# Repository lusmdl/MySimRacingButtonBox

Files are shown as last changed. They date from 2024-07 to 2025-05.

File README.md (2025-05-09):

# Sim Racing Button Box

Welcome to the Sim Racing Button Controller repository!  

This project is built around an ATmega328P microcontroller, which is configured to manage a button matrix tailored for sim racing setups. 
The system uses I2C communication, where the Arduino Micro acts as the **master** and the ATmega328P functions as the **slave** (Address standard 8).
This ensures precise control and synchronization between the components.  

The ATmega328P transmits a 16-bit signal representing the states of up to 16 buttons **only when requested by the Arduino Micro**. This on-demand communication minimizes latency and ensures efficient data transfer. Additionally, the PCB includes support for a joystick connection, expanding its versatility.  

This project complements [MySimRacingCore](https://github.com/lusmdl/MySimRacingCore), which serves as the brain of the entire sim racing system. Together, they deliver a modular and high-performance solution for sim racing enthusiasts.

## Features

- Support for up to 16 buttons in a matrix configuration
- Seamless I2C communication with the Arduino Micro for precise control
- Fast and effective button state management with Keypad Library
- Joystick integration via the PCB's RJ45 jack, reducing wiring complexity

## Getting Started

### Hardware Requirements

- **ATmega328P Microcontroller**
- 16 Mhz Oscilator
- 12..22 pF Condansator
- 100 µF Condansator for supply stability
- **Button Matrix**: Up to 16 buttons
- **The PCBA from master project**: [MySimRacingCore](https://github.com/lusmdl/MySimRacingCore)

> Example PCB for this project
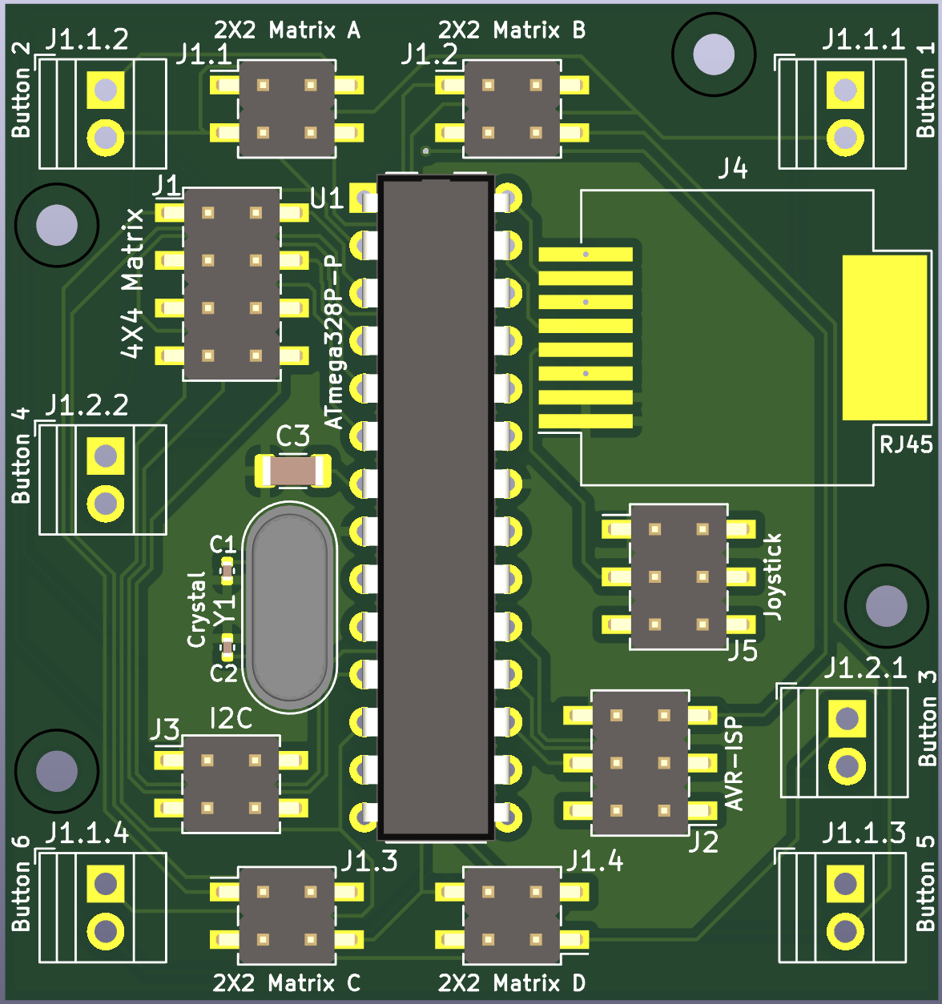
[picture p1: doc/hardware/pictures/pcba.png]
PCBA


### Software Requirements

- [**PlatformIO**](https://platformio.org/install/ide?install=vscode): Used for programming the ATmega328P microcontroller.
- [**Wire.h**](https://www.arduino.cc/en/Reference/Wire): for I2C communication
- [**AVR Lib**](https://github.com/avrdudes/avr-libc.git): standard lib with PlatformIO.
- [**Keypad Library**](https://github.com/Chris--A/Keypad.git): Used for the 4x4 Matrix

### Software Installation and Setup

> You can either use the precompiled HEX file or compile the firmware yourself.

1. **Install PlatformIO**  
   - Set up PlatformIO in your preferred development environment (e.g., VSCode or Atom) by following the official [installation guide](https://platformio.org/install).  

2. **Clone the Repository**  

   ```sh
   git clone https://github.com/lusmdl/MySimRacingButtonBox.git
   ```  

**3. Open the Project**  
- Open the cloned repository in your PlatformIO environment.  
- Update the line `#define I2C_ADDR            8` in [ProjectConfig.hpp](/include/ProjectConfig.hpp) to match your I²C master device configuration.

> The default address is 8. If you intend to connect this device twice, use addresses 8 and 9. The master will handle the rest.

4. **Build and Upload**  
   - Prepare your ATmega328P-based PCB for flashing. It’s recommended to first flash the firmware onto an Arduino Uno and then transfer the chip to your custom environment.  
   - Build and upload the code using PlatformIO:  

   ```sh
   pio run --target upload
   ```  

### Hardware Setup

1. Assemble the PCB according to the provided design.  
2. Ensure all components, such as the button matrix and joystick, are correctly connected.

## Usage

1. **Hardware Connection**  
   - Connect the button matrix to the ATmega328P as per the configuration.  
   - Establish an I2C connection between the ATmega328P and the Arduino Micro.  

2. **Running the Firmware**  
   - Power on your system.  
   - The ATmega328P will only send a 16-bit signal to the Arduino Micro when requested over I2C, ensuring efficient communication.

## Documentation

- **Software**: [doc/software/html/index.html](doc/software/html/index.html)

## Contributing

We welcome contributions from the community!

First, read the [general contributing conventions for projects from me](CONTRIBUTING.md).

1. Fork the repository.
2. Create a new branch (`git checkout -b feature-branch`).
3. Commit your changes (`git commit -am 'Add new feature'`).
4. Push to the branch (`git push origin feature-branch`).
5. Create a new Pull Request.

## License

This project is licensed under the MIT License - see the [LICENSE](LICENSE) file for details.

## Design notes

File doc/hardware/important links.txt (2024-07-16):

https://docs.arduino.cc/learn/communication/wire/

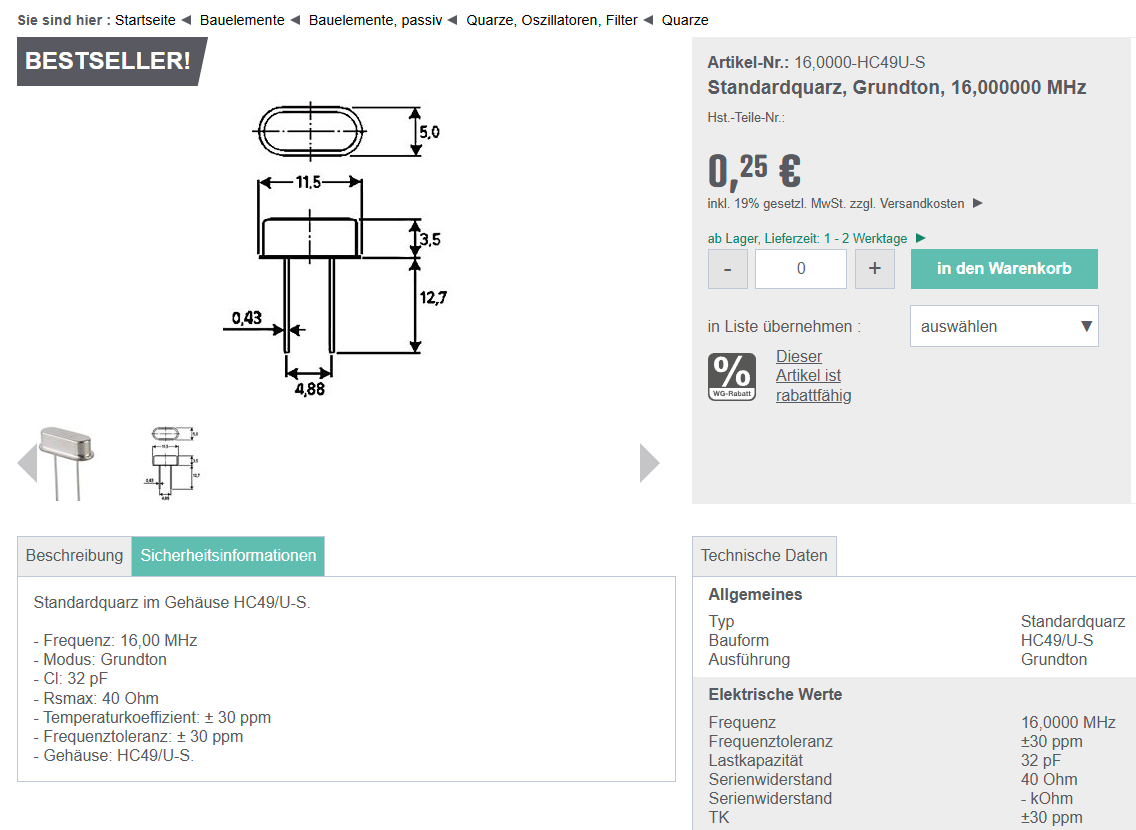
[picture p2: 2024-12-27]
doc/hardware/16mhz Quarz.png

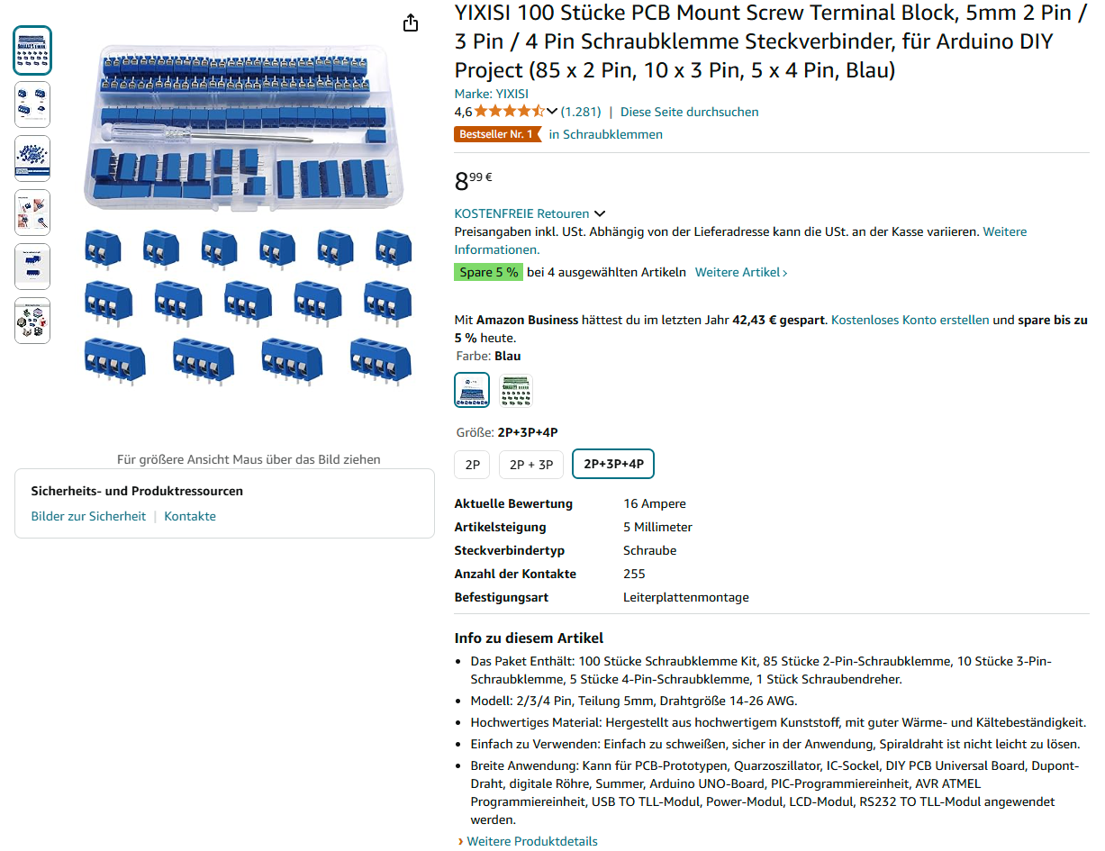
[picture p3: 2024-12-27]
doc/hardware/Srew terminal block.png

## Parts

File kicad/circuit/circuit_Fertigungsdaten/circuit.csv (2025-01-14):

ID | Bezeichner | Footprint | Stückzahl | Bezeichnung | Anbieter und Referenz
1 | J1.1.3 | TerminalBlock_Xinya_XY308-2.54-2P_1x02_P2.54mm_Horizontal | 1 | Button 5
2 | J1.1.1 | TerminalBlock_Xinya_XY308-2.54-2P_1x02_P2.54mm_Horizontal | 1 | Button 1
3 | J1.3 | PinHeader_2x02_P2.54mm_Vertical_SMD | 1 | 2X2 Matrix C
4 | C2,C1 | C_0402_1005Metric | 2 | 12..22 pF
5 | J3 | PinHeader_2x02_P2.54mm_Vertical_SMD | 1 | I2C
6 | J5 | PinHeader_2x03_P2.54mm_Vertical_SMD | 1 | Joystick
7 | J1.1.2 | TerminalBlock_Xinya_XY308-2.54-2P_1x02_P2.54mm_Horizontal | 1 | Button 2
8 | J4 | RJ45_Molex_0855135013_Vertical | 1 | RJ45
9 | J1.2.2 | TerminalBlock_Xinya_XY308-2.54-2P_1x02_P2.54mm_Horizontal | 1 | Button 4
10 | U1 | DIP-28_W7.62mm | 1 | ATmega328P-P
11 | J2 | PinHeader_2x03_P2.54mm_Vertical_SMD | 1 | AVR-ISP
12 | J1.2 | PinHeader_2x02_P2.54mm_Vertical_SMD | 1 | 2X2 Matrix B
13 | Y1 | Crystal_HC18-U_Vertical | 1 | Crystal
14 | J1.2.1 | TerminalBlock_Xinya_XY308-2.54-2P_1x02_P2.54mm_Horizontal | 1 | Button 3
15 | J1.4 | PinHeader_2x02_P2.54mm_Vertical_SMD | 1 | 2X2 Matrix D
16 | J1 | PinHeader_2x04_P2.54mm_Vertical_SMD | 1 | 4X4 Matrix
17 | J1.1.4 | TerminalBlock_Xinya_XY308-2.54-2P_1x02_P2.54mm_Horizontal | 1 | Button 6
18 | C3 | C_1206_3216Metric | 1 | 10 µF
19 | J1.1 | PinHeader_2x02_P2.54mm_Vertical_SMD | 1 | 2X2 Matrix A

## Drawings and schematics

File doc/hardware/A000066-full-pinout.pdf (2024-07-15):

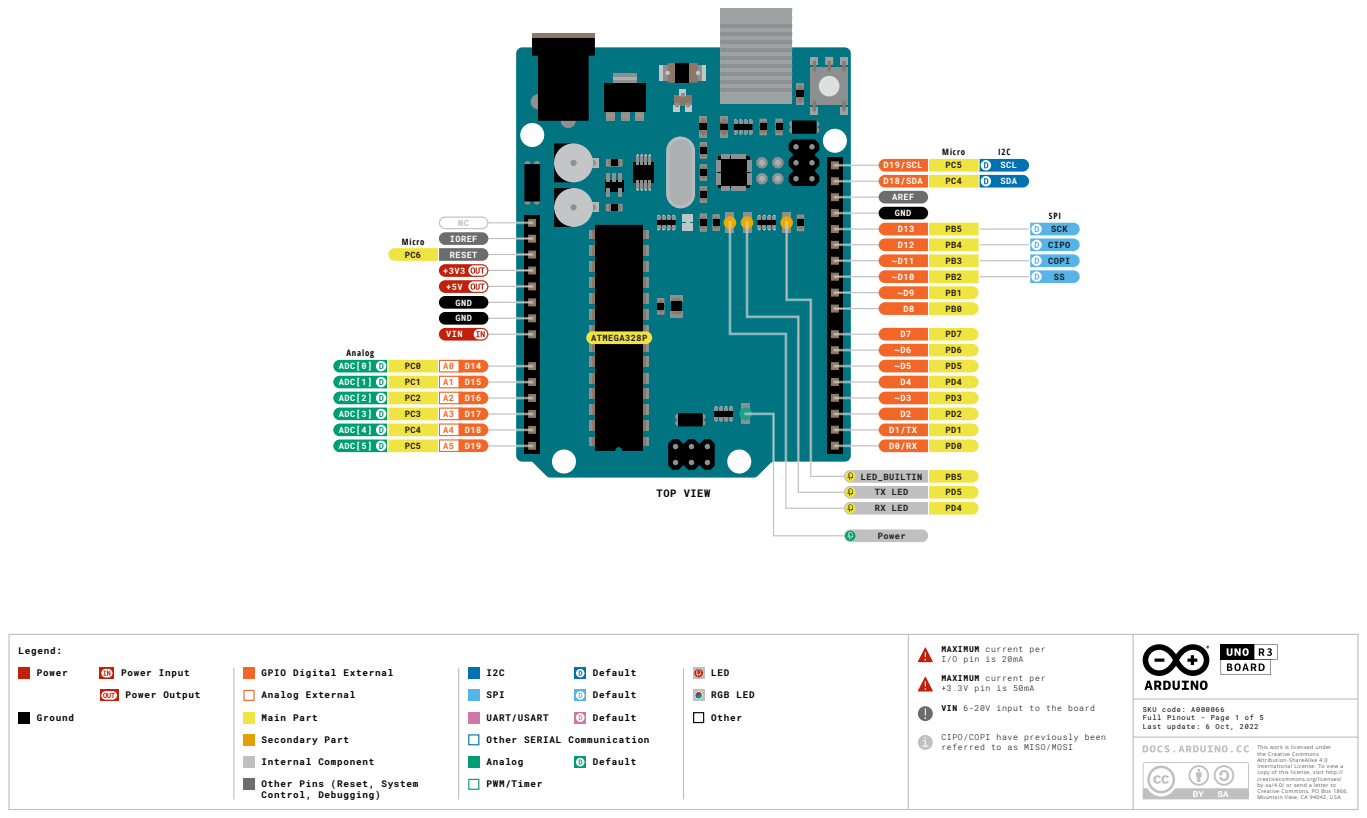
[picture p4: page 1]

PC2 | A2
PC3 | A3

MAXIMUM current per
I/O pin is 20mA
+3.3V pin is 50mA
VIN 6-20V input to the board

GPIO Digital External
Analog External
Main Part
Secondary Part
Internal Component
Other Pins (Reset, System
Control, Debugging)

SKU code: A000066
Full Pinout - Page 1 of 5
Last update: 6 Oct, 2022

CIPO/COPI have previously been
referred to as MISO/MOSI

This work is licensed under
the Creative Commons
Attribution-ShareAlike 4.0
International License. To view a
copy of this license, visit http://
creativecommons.org/licenses/
by-sa/4.0/ or send a letter to
Creative Commons, PO Box 1866,
Mountain View, CA 94042, USA.

# WARNING!

# Advanced Section

# The following information is for advanced use only and may not be officially supported by Arduino software

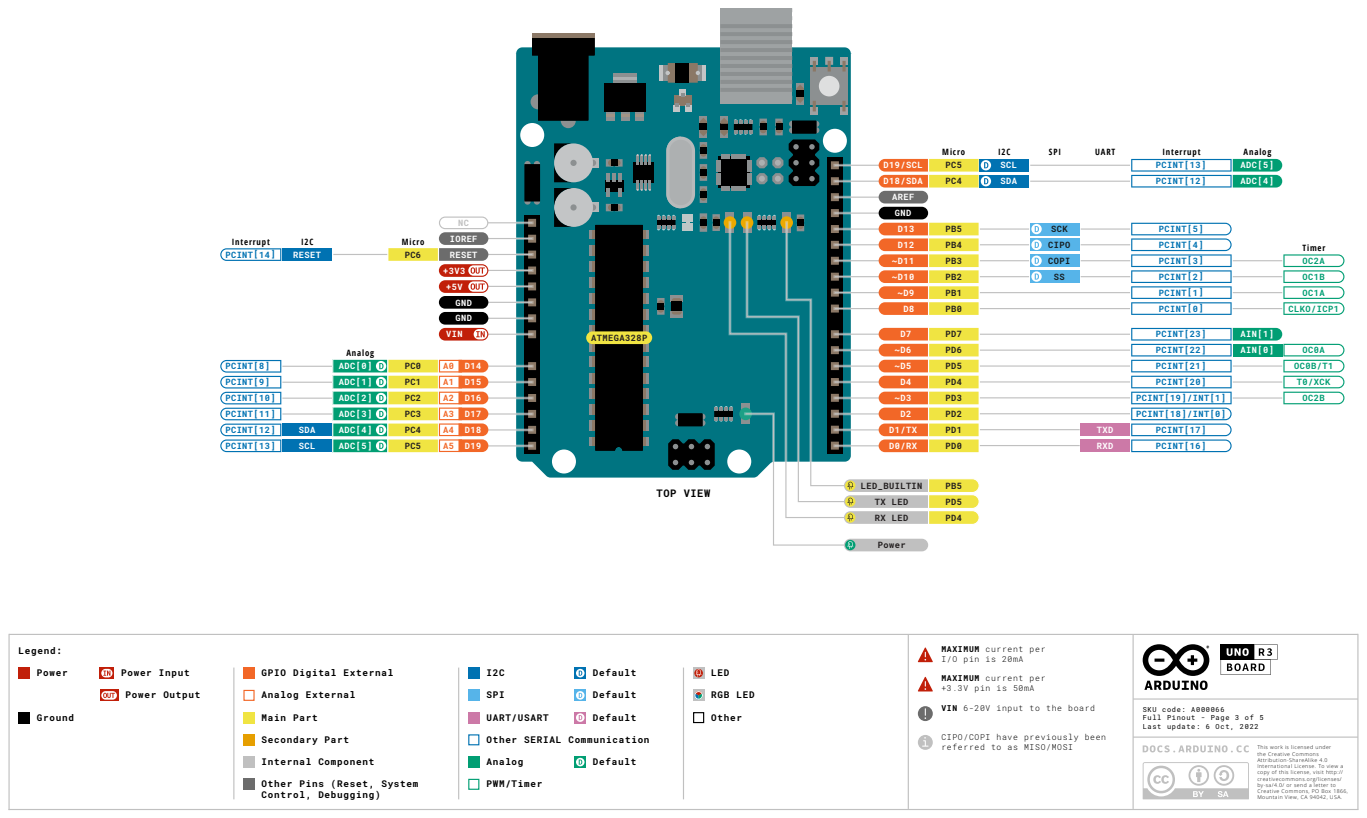
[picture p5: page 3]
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

SKU code: A000066
Full Pinout - Page 3 of 5
Last update: 6 Oct, 2022

CIPO/COPI have previously been

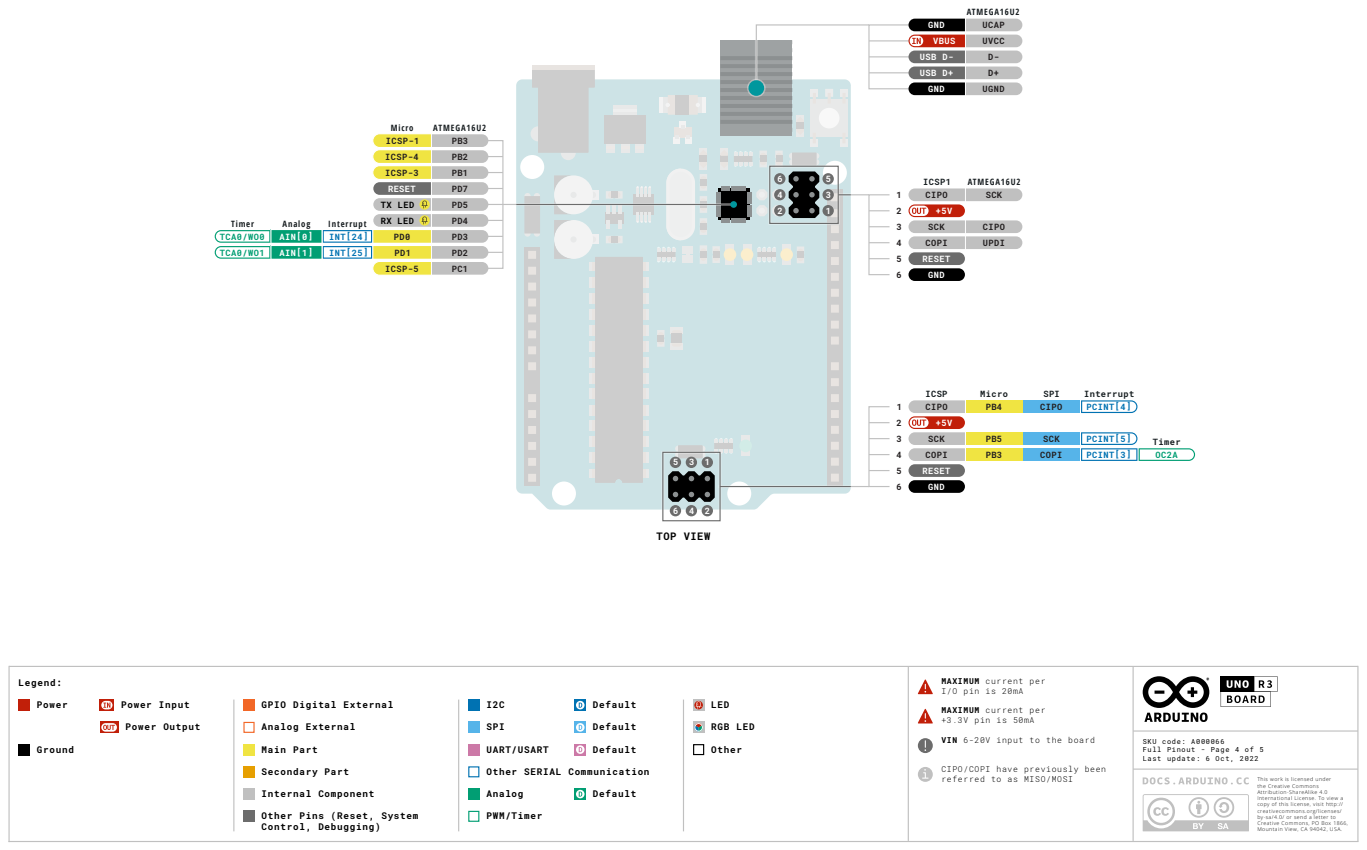
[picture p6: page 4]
Legend:; Power; Power Input; Power Output; Ground; Default; SPI; UART/USART; LED; RGB LED; Other; TOP VIEW; Micro; ATMEGA16U2; Timer; Analog; Interrupt; TCA0/WO0 TCA0/WO1; ICSP-1 ICSP-4 ICSP-3 RESET TX LED RX LED PD0 PD1 ICSP-5; INT[24] INT[25]; AIN[0] AIN[1]; SCK; CIPO UPDI; 1 CIPO 2 +5V 3 SCK 4 COPI 5 RESET 6 GND; ICSP1; ICSP; CIPO; COPI; PCINT[4]; PCINT[5] PCINT[3]; GND; UCAP; VBUS; UVCC; USB D-; USB D+; UGND

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

GPIO Digital External
Analog External
Main Part
Secondary Part

Other SERIAL Communication

SKU code: A000066
Full Pinout - Page 4 of 5
Last update: 6 Oct, 2022

CIPO/COPI have previously been

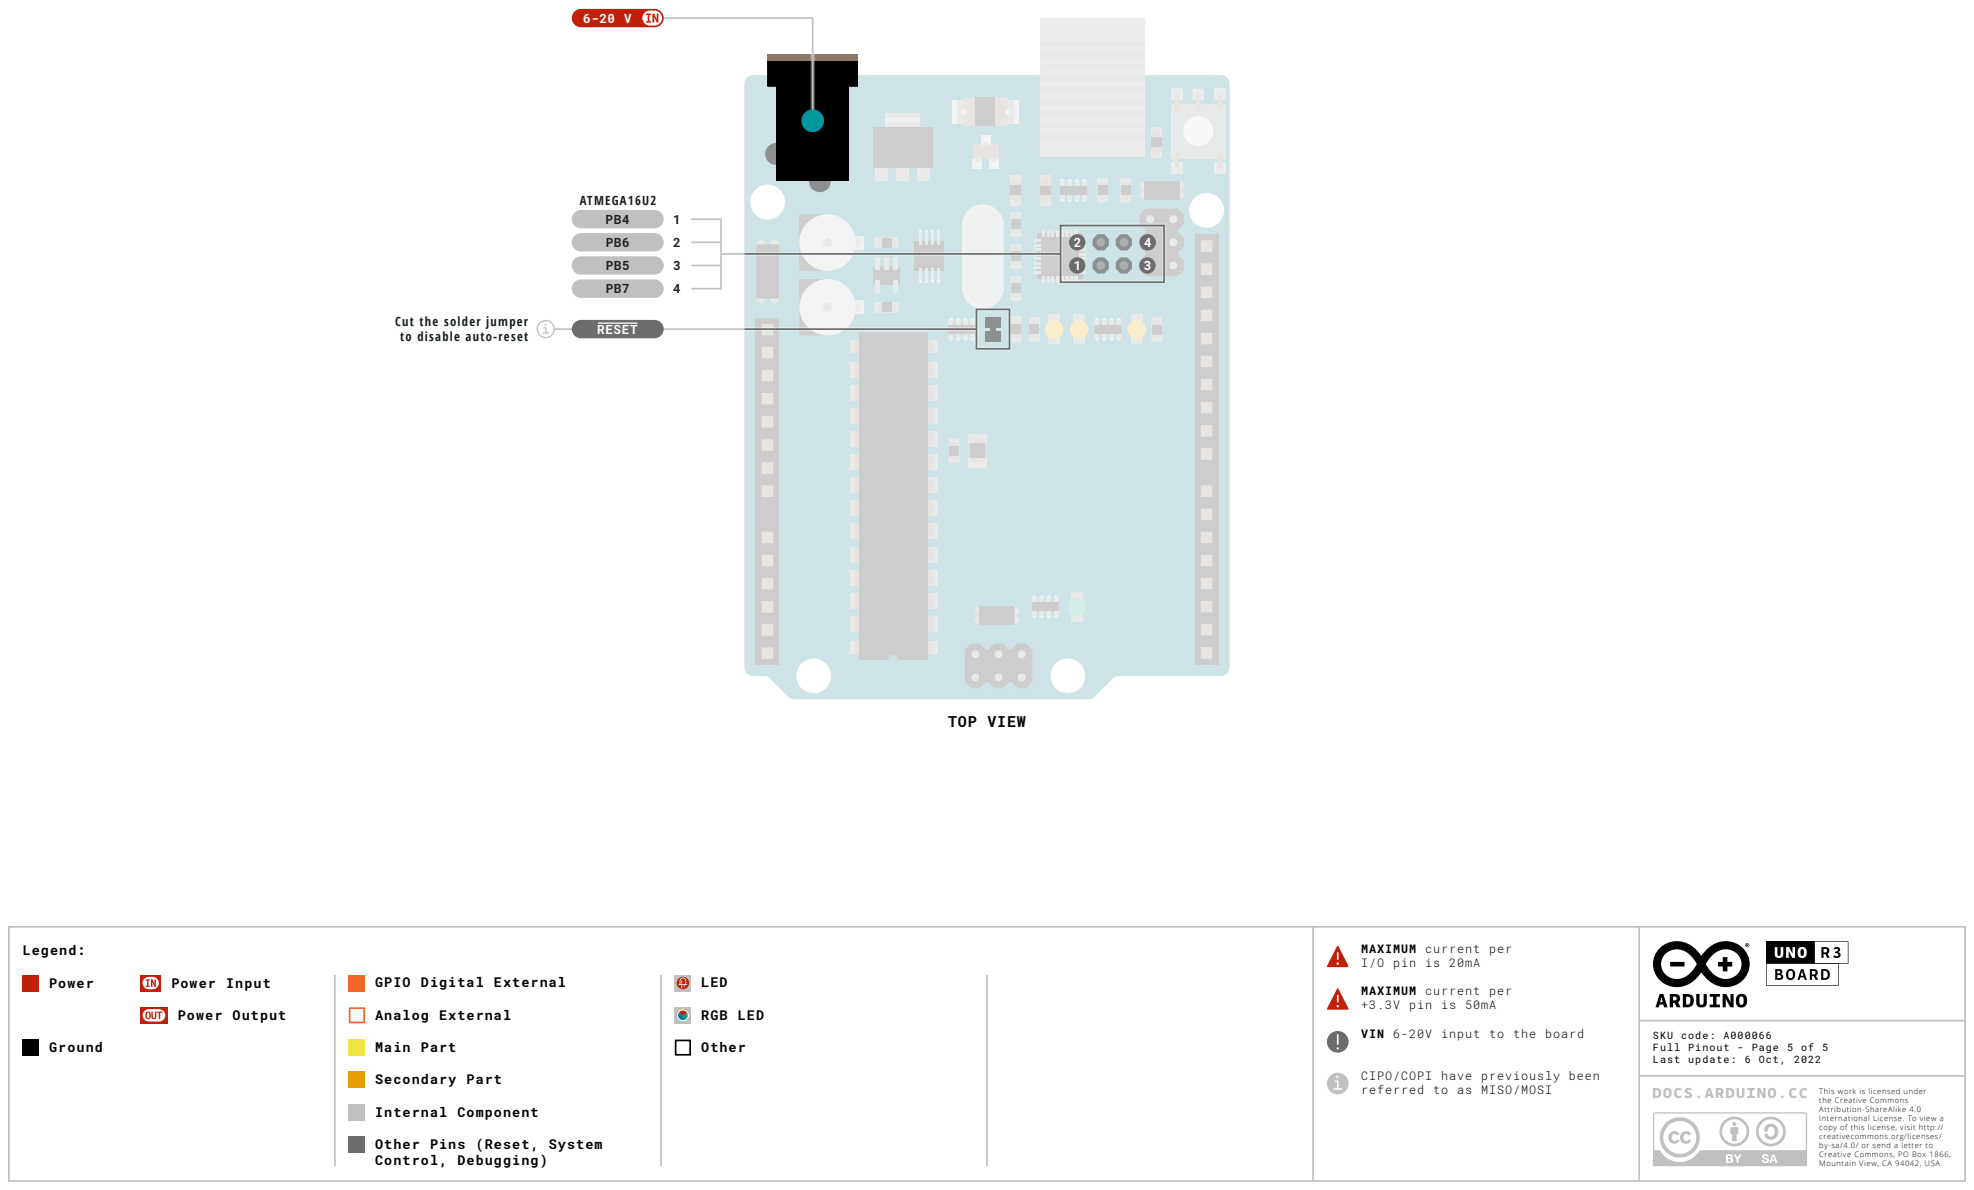
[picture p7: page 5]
Legend:; Power; Power Input; Power Output; Ground; LED; RGB LED; Other; TOP VIEW; ATMEGA16U2 PB4 PB6 PB5 PB7; RESET

Cut the solder jumper
to disable auto-reset

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

GPIO Digital External
Analog External
Main Part
Secondary Part

SKU code: A000066
Full Pinout - Page 5 of 5
Last update: 6 Oct, 2022

CIPO/COPI have previously been

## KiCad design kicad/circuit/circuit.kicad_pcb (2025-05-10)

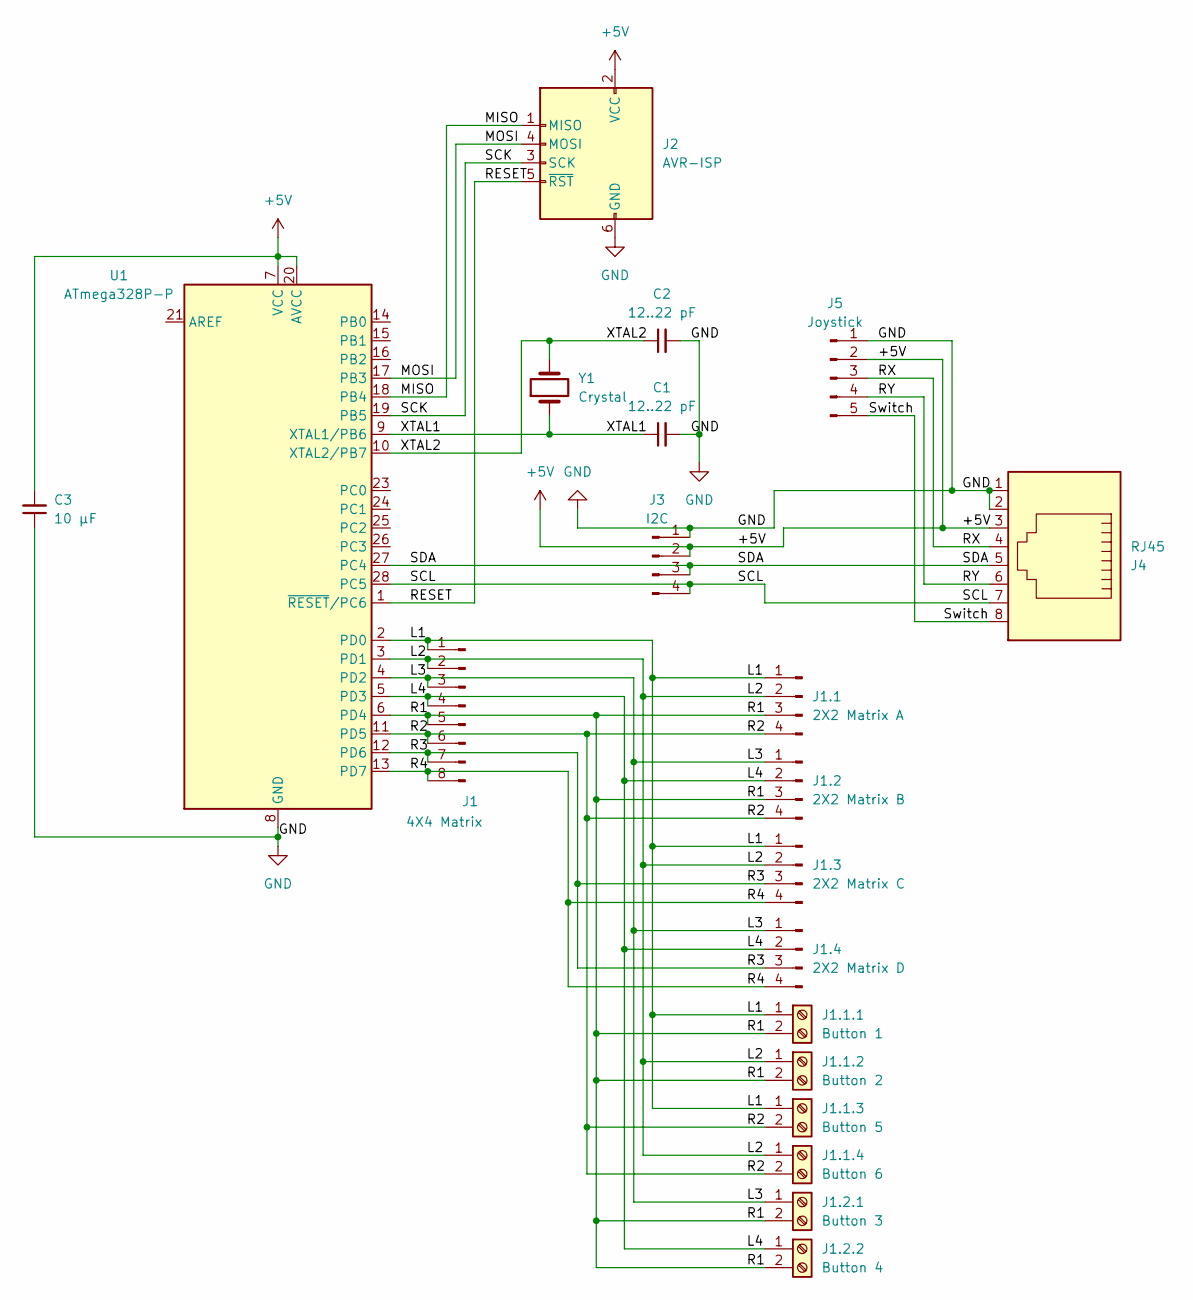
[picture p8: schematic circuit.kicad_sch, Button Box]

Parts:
C1, C2: 12..22 pF; C_0402_1005Metric
C3: 10 µF; C_1206_3216Metric
J1: 4X4 Matrix; PinHeader_2x04_P2.54mm_Vertical_SMD
J1.1: 2X2 Matrix A; PinHeader_2x02_P2.54mm_Vertical_SMD
J1.1.1: Button 1; TerminalBlock_Xinya_XY308-2.54-2P_1x02_P2.54mm_Horizontal
J1.1.2: Button 2; TerminalBlock_Xinya_XY308-2.54-2P_1x02_P2.54mm_Horizontal
J1.1.3: Button 5; TerminalBlock_Xinya_XY308-2.54-2P_1x02_P2.54mm_Horizontal
J1.1.4: Button 6; TerminalBlock_Xinya_XY308-2.54-2P_1x02_P2.54mm_Horizontal
J1.2: 2X2 Matrix B; PinHeader_2x02_P2.54mm_Vertical_SMD
J1.2.1: Button 3; TerminalBlock_Xinya_XY308-2.54-2P_1x02_P2.54mm_Horizontal
J1.2.2: Button 4; TerminalBlock_Xinya_XY308-2.54-2P_1x02_P2.54mm_Horizontal
J1.3: 2X2 Matrix C; PinHeader_2x02_P2.54mm_Vertical_SMD
J1.4: 2X2 Matrix D; PinHeader_2x02_P2.54mm_Vertical_SMD
J2: AVR-ISP; PinHeader_2x03_P2.54mm_Vertical_SMD
J3: I2C; PinHeader_2x02_P2.54mm_Vertical_SMD
J4: RJ45; RJ45_Molex_0855135013_Vertical
J5: Joystick; PinHeader_2x03_P2.54mm_Vertical_SMD
U1: ATmega328P-P; DIP-28_W7.62mm
Y1: Crystal; Crystal_HC18-U_Vertical

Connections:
+5V: C3.2, J2.2 (VCC), J3.2, J4.3, J5.2, U1.7 (VCC), U1.20 (AVCC)
/L1: J1.1, J1.1.1, J1.1.1.1, J1.1.3.1, J1.3.1, U1.2 (PD0)
/L2: J1.2, J1.1.2, J1.1.2.1, J1.1.4.1, J1.3.2, U1.3 (PD1)
/L3: J1.3, J1.2.1, J1.2.1.1, J1.4.1, U1.4 (PD2)
/L4: J1.4, J1.2.2, J1.2.2.1, J1.4.2, U1.5 (PD3)
/MISO: J2.1 (MISO), U1.18 (PB4)
/MOSI: J2.4 (MOSI), U1.17 (PB3)
/R1: J1.5, J1.1.3, J1.1.1.2, J1.1.2.2, J1.2.3, J1.2.1.2, J1.2.2.2, U1.6 (PD4)
/R2: J1.6, J1.1.4, J1.1.3.2, J1.1.4.2, J1.2.4, U1.11 (PD5)
/R3: J1.7, J1.3.3, J1.4.3, U1.12 (PD6)
/R4: J1.8, J1.3.4, J1.4.4, U1.13 (PD7)
/RESET: J2.5 (~RST), U1.1 (~RESET/PC6)
/RX: J4.4, J5.3
/RY: J4.6, J5.4
/SCK: J2.3 (SCK), U1.19 (PB5)
/SCL: J3.4, J4.7, U1.28 (PC5)
/SDA: J3.3, J4.5, U1.27 (PC4)
/Switch: J4.8, J5.5
/XTAL1: C1.1, U1.9 (XTAL1/PB6), Y1.1
/XTAL2: C2.1, U1.10 (XTAL2/PB7), Y1.2
GND: C1.2, C2.2, C3.1, J2.6 (GND), J3.1, J4.1, J4.2, J5.1, U1.8 (GND), U1.22 (GND)

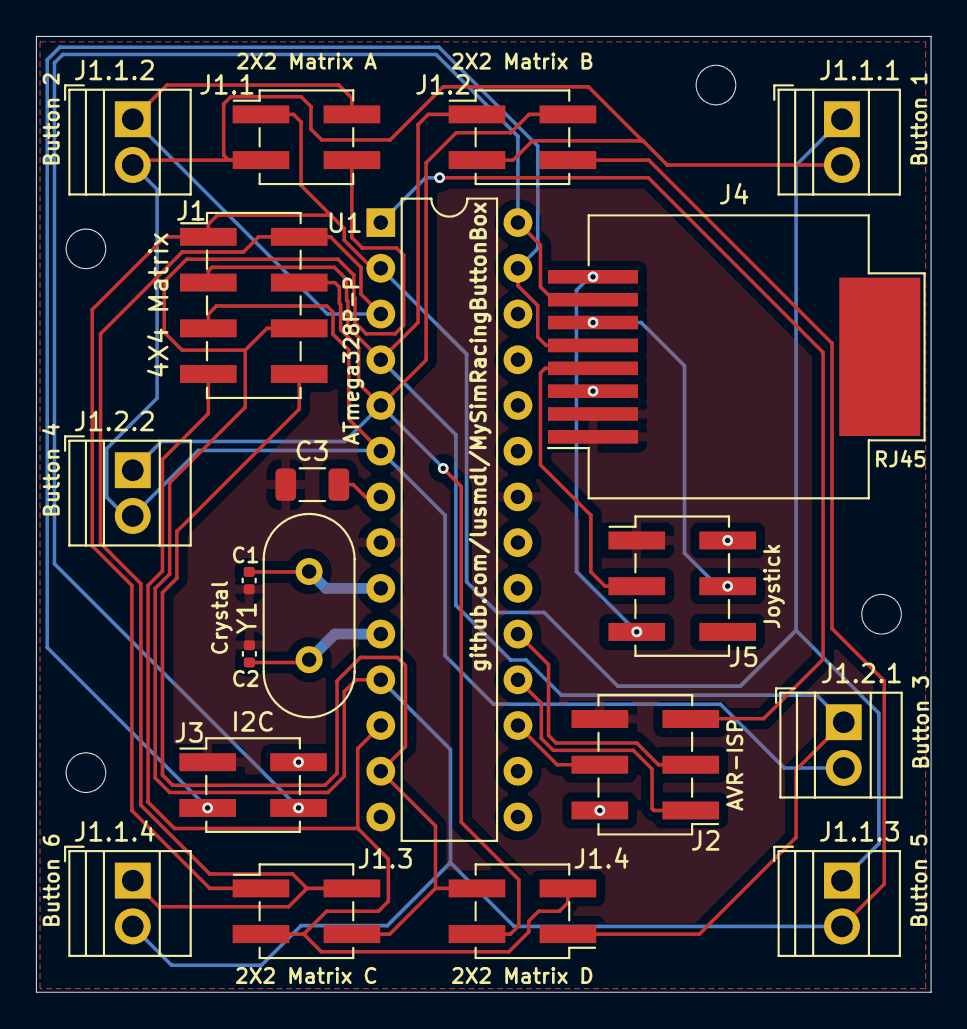
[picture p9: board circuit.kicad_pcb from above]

Board: 2 copper layers, 49.7 x 53.1 mm, 20 parts (0 on the bottom side), 21 nets.

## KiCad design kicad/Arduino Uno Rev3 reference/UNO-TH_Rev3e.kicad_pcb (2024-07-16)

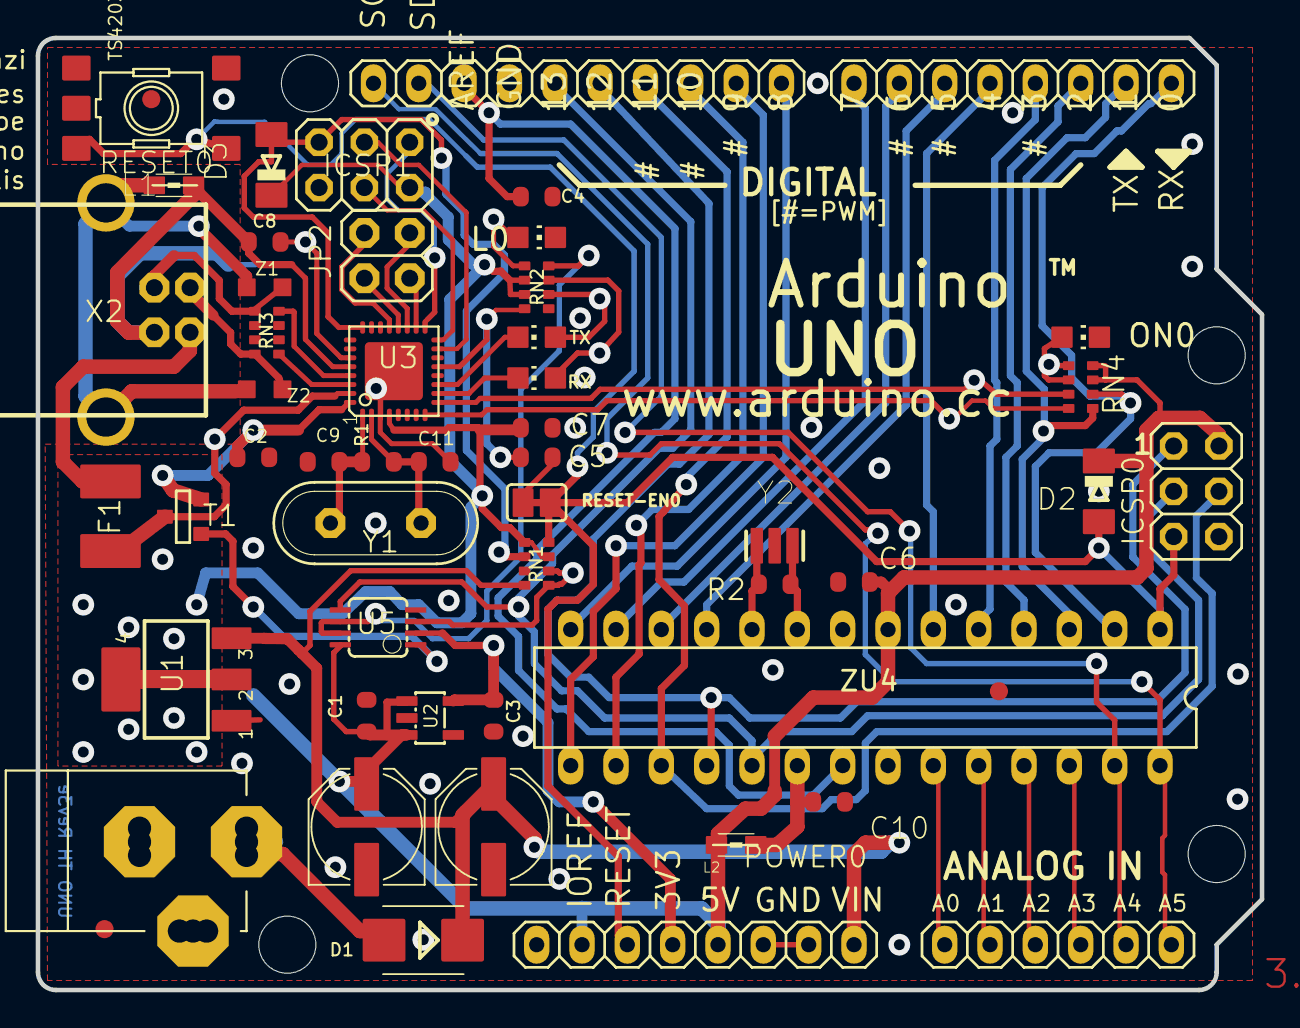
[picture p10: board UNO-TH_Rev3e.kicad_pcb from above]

Board: 2 copper layers, 68.6 x 53.3 mm, 120 parts (1 on the bottom side), 61 nets.

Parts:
@HOLE0, @HOLE1, @HOLE2, @HOLE3: (no value)
AD0: 6x1F-H8.5; 1X06
C1, C2, C4, C5, C6, C7, C10: 100n; C0603-ROUND
C3, C8: 1u; C0603-ROUND
C9, C11: 22p; C0603-ROUND
D1: M7; SMB
D2, D3: CD1206-S01575; MINIMELF
F1: MF-MSMF050-2 500mA; L1812
FD1, FD2, FD3: FIDUCIALMOUNT; FIDUCIA-MOUNT
FRAME1: DNP; FRAME
GND_TP0, GND_TP1: TP_SP; TP-SP
GROUND0: SJ
ICSP0, ICSP1: 3x2 M; 2X03
IOH0: 10x1F-H8.5; 1X10
IOL0: 8x1F-H8.5; 1X08
JP2: 2x2 M - NM; 2X02
L0: YELLOW; CHIP-LED0805
L1: BLM21; 0805
L2: 10uH; 0805
ON0: GREEN; CHIP-LED0805
ORIGIN0: TP_SP; TP-SP
PC1, PC2: 47u; PANASONIC_D
POWER0: 8x1F-H8.5; 1X08
R1, R2: 1M; R0603-ROUND
RESET0: TS42031-160R-TR-7260; TS42
RESET-EN0: SJ
RN1: 10K; CAY16
RN2, RN4: 1K; CAY16
RN3: 22R; CAY16
RX0: YELLOW; CHIP-LED0805
T1: FDN340P; SOT-23
TP_0, TP_1, TP_2, TP_3, TP_3V3, TP_4, TP_5, TP_5V0, TP_5V1, TP_6, TP_7, TP_8, TP_9, TP_10, TP_11, TP_12, TP_13: TP_SP; TP-SP
TP_A0, TP_A1, TP_A2, TP_A3, TP_A4, TP_A5: TP_SP; TP-SP
TP_AREF0: TP_SP; TP-SP
TP_CMP0: TP_SP; TP-SP
TP_D+0: TP_SP; TP-SP
TP_D-0: TP_SP; TP-SP
TP_DTR0: TP_SP; TP-SP
TP_GATE0: TP_SP; TP-SP
TP_LCMD0: TP_SP; TP-SP
TP_LL0: TP_SP; TP-SP
TP_MISO2: TP_SP; TP-SP
TP_MOSI2: TP_SP; TP-SP
TP_ONL0: TP_SP; TP-SP
TP_PB4, TP_PB5, TP_PB6, TP_PB7: TP_SP; TP-SP
TP_PWRIN0: TP_SP; TP-SP
TP_RESET0, TP_RESET2: TP_SP; TP-SP
TP_RX0: TP_SP; TP-SP
TP_RXL0: TP_SP; TP-SP
TP_SCK2: TP_SP; TP-SP
TP_SCL0: TP_SP; TP-SP
TP_SDA0: TP_SP; TP-SP
TP_TX0: TP_SP; TP-SP
TP_TXL0: TP_SP; TP-SP
TP_UGND0: TP_SP; TP-SP
TP_USBVCC0: TP_SP; TP-SP
TP_USH0: TP_SP; TP-SP
TP_VIN0: TP_SP; TP-SP
TP_VUCAP0: TP_SP; TP-SP
TP_XT1, TP_XT2, TP_XT3, TP_XT4: TP_SP; TP-SP
TP_XUSB0: TP_SP; TP-SP
TX0: YELLOW; CHIP-LED0805
U1: NCP1117ST50T3G; SOT223
U2: LP2985-33DBVR; SOT23-DBV
U3: ATMEGA16U2-MU(R); MLF32
U5: LMV358IDGKR; MSOP08
X1: POWERSUPPLY_DC21MMX; POWERSUPPLY_DC-21MM
X2: USB-B_TH; PN61729
Y1: 16MHz; QS
Y2: CSTCE16M0V53-R0 16MHZ; RESONATOR
Z1, Z2: CG0603MLC-05E; CT_CN0603
ZU4: ATMEGA328P-PU; DIL28-3

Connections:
+3V3: C3.2, POWER0.4, TP_3V3.X, U2.5, U5.2
+5V: C1.2, C2.2, C6.2, C7.1, D2.C, D3.C, ICSP0.2, ICSP1.2, L2.1, PC2.+, POWER0.2, POWER0.5, RN1.3, RN1.5, RN2.2, RN2.3, RN4.3, RN4.4, T1.2, TP_5V0.X, TP_5V1.X, U1.2, U1.4, U2.1, U2.3, U3.4, U3.32, U5.8, ZU4.7
AD0: AD0.1, TP_A0.X, ZU4.23
AD1: AD0.2, TP_A1.X, ZU4.24
AD2: AD0.3, TP_A2.X, ZU4.25
AD3: AD0.4, TP_A3.X, ZU4.26
AD4/SDA: AD0.5, IOH0.9, TP_A4.X, TP_SDA0.X, ZU4.27
AD5/SCL: AD0.6, IOH0.10, TP_A5.X, TP_SCL0.X, ZU4.28
AREF: C4.2, IOH0.8, TP_AREF0.X, ZU4.21
AVCC: C10.2, L2.2, ZU4.20
CMP: RN1.1, RN1.2, TP_CMP0.X, U5.3
D+: RN3.5, TP_D+0.X, X2.3, Z1.1
D-: RN3.8, TP_D-0.X, X2.2, Z2.1
DTR: C5.1, RN2.4, TP_DTR0.X, U3.13
GATE_CMD: T1.3, TP_GATE0.X, U5.1
GND: C1.1, C2.1, C3.1, C4.1, C6.1, C7.2, C9.2, C10.1, C11.2, GND_TP0.X, GND_TP1.X, GROUND0.1, ICSP0.6, ICSP1.6, IOH0.7, L0.C, ON0.C, PC1.-, PC2.-, POWER0.6, POWER0.7, RESET0.1, RESET0.2, RN1.7, RN2.5, U1.1, U2.2, U3.3, U3.33, U5.4, X1.1, X1.3, Y2.2, ZU4.8, ZU4.22
IO0: IOL0.1, RN4.2, TP_0.X, ZU4.2
IO1: IOL0.2, RN4.1, TP_1.X, ZU4.3
IO2: IOL0.3, TP_2.X, ZU4.4
IO3: IOL0.4, TP_3.X, ZU4.5
IO4: IOL0.5, TP_4.X, ZU4.6
IO5: IOL0.6, TP_5.X, ZU4.11
IO6: IOL0.7, TP_6.X, ZU4.12
IO7: IOL0.8, TP_7.X, ZU4.13
IO8: IOH0.1, TP_8.X, ZU4.14
IO9: IOH0.2, TP_9.X, ZU4.15
L13: RN2.8, TP_LCMD0.X, U5.6, U5.7
M8RXD: RN4.7, TP_RX0.X, U3.9
M8TXD: RN4.8, TP_TX0.X, U3.8
MISO: ICSP0.1, IOH0.5, TP_12.X, ZU4.18
MISO2: ICSP1.1, TP_MISO2.X, U3.17
MOSI: ICSP0.4, IOH0.4, TP_11.X, ZU4.17
MOSI2: ICSP1.4, TP_MOSI2.X, U3.16
unnamed: L0.A, RN2.1, TP_LL0.X
unnamed: ON0.A, RN4.5, RN4.6, TP_ONL0.X
unnamed: RN2.7, RX0.A, TP_RXL0.X
unnamed: RN2.6, TP_TXL0.X, TX0.A
PB4: JP2.1, TP_PB4.X, U3.18
PB5: JP2.3, TP_PB5.X, U3.19
PB6: JP2.2, TP_PB6.X, U3.20
PB7: JP2.4, TP_PB7.X, U3.21
PWRIN: D1.A, TP_PWRIN0.X, X1.2
RD+: RN3.4, U3.29
RD-: RN3.1, U3.30
RESET: C5.2, D2.A, ICSP0.5, POWER0.3, RESET0.3, RESET0.4, RESET-EN0.1, RESET-EN0.2, RN1.4, TP_RESET0.X, ZU4.1
RESET2: D3.A, ICSP1.5, RN1.6, TP_RESET2.X, U3.24
RXLED: RX0.C, U3.10
SCK: ICSP0.3, IOH0.6, TP_13.X, U5.5, ZU4.19
SCK2: ICSP1.3, TP_SCK2.X, U3.15
SS: IOH0.3, TP_10.X, ZU4.16
TP_VUCAP: C8.1, TP_VUCAP0.X, U3.27
TXLED: TX0.C, U3.11
UGND: C8.2, GROUND0.2, L1.1, TP_UGND0.X, U3.28, X2.4
USBVCC: F1.1, T1.1, TP_USBVCC0.X, U3.31
USHIELD: L1.2, TP_USH0.X, X2.P$1, X2.P$2, Z1.2, Z2.2
VIN: D1.C, PC1.+, POWER0.8, RN1.8, TP_VIN0.X, U1.3
XT1: C9.1, R1.1, TP_XT3.X, U3.1, Y1.2
XT2: C11.1, R1.2, TP_XT4.X, U3.2, Y1.1
XTAL1: R2.1, TP_XT1.X, Y2.3, ZU4.9
XTAL2: R2.2, TP_XT2.X, Y2.1, ZU4.10
XUSB: F1.2, TP_XUSB0.X, X2.1

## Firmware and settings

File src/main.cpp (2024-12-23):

/**
 * @file main.cpp
 * @brief Demonstrates I2C communication with a button matrix using the `Buttons` and `ComI2C` classes.
 * 
 * This program initializes a button matrix and configures I2C communication to send the state of 
 * the buttons to an I2C master device. The button matrix is continuously monitored, and the state 
 * is sent whenever the master requests data.
 * 
 * @details
 * - `Buttons`: Manages the button matrix.
 * - `ComI2C`: Handles I2C communication.
 * - The I2C address is defined in the `\include\ProjectConfig.hpp` file to avoid conflicts with other devices.
 */

#include <Arduino.h>
#include "ProjectConfig.hpp"
#include "WheelButtons/Buttons.hpp"
#include "WheelButtons/ComI2C.hpp"

// Global instances for the button matrix and I2C communication.

Buttons buttons;
ComI2C i2c(Wire, buttons);

void requestEvent();

/**
 * @brief  Arduino setup function. Runs once at startup.
 * 
 * This function initializes the Serial debug output (if enabled), the button 
 * matrix, and the I2C communication. It ensures that the `Buttons` and `ComI2C` 
 * classes are properly configured.
 */
void setup() {

  // put your setup code here, to run once:

  #ifdef LUSMDL_DEBUGMODE
  Serial.begin(9600);
  Serial.print("setup\n");
  #endif

  // init buttons
  buttons.begin();

  // init the I2C communication as a Slave
  // it is important to change the Address in the '\include\ProjectConfig.hpp' so that no slave have the same adress
  i2c.begin(I2C_ADDR,requestEvent);

}

/**
 * @brief  Arduino loop function. Runs continuously after setup.
 * 
 * This function continuously listens for button events by calling the 
 * `Buttons::listener` method.
 */
void loop() {

  // put your main code here, to run repeatedly:
  // the only task is to listen for any buttons

  buttons.listener();
}

/**
 * @brief  Handles I2C data requests from the master.
 * 
 * This function is called whenever the I2C master requests data. It retrieves 
 * the state of all buttons from the `Buttons` class and sends it over I2C 
 * using the `ComI2C` class.
 */
void requestEvent() {

  // get called every time the master requests data

  i2c.event();
}

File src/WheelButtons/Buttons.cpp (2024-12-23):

/**
 * @file Buttons.cpp
 * @brief Implementation of the Buttons class.
 */

#include "Buttons.hpp"

/**
 * @brief  Initializes the Buttons class.
 * 
 * The constructor sets up the button matrix with specified row and column pins, 
 * and initializes the keymap for detecting button presses. The key names are 
 * derived using the `getmap` method to ensure correctness.
 * 
 * @details
 * - `rowpins_`: Array of GPIO pins corresponding to the button matrix rows.
 * - `columnspins_`: Array of GPIO pins corresponding to the button matrix columns.
 * - `keyarray_`: A 2D array representing the button layout. Each key is mapped using `getmap`.
 * - `keys_`: Handles key events using the mapped key array, row pins, and column pins.
 * - `lasteventkey_`: Tracks the last key event (initialized to '\0').
 */
Buttons::Buttons() :
    rowpins_{BTN_MATRIX_R1, BTN_MATRIX_R2, BTN_MATRIX_R3, BTN_MATRIX_R4},
    columnspins_{BTN_MATRIX_L1, BTN_MATRIX_L2, BTN_MATRIX_L3, BTN_MATRIX_L4},
    keyarray_{ // The getmap method ensures the key names are correct
        {getmap(0),     getmap(1),  getmap(2),      getmap(3)},
        {getmap(4),     getmap(5),  getmap(6),      getmap(7)},
        {getmap(8),     getmap(9),  getmap(10),     getmap(11)},
        {getmap(12),    getmap(13), getmap(14),     getmap(15)}
    },
    keys_(makeKeymap(keyarray_), rowpins_, columnspins_, BTN_MATRIX_R, BTN_MATRIX_L),
    lasteventkey_('\0')
{}

/**
 * @brief  Destructor for the Buttons class.
 * 
 * Cleans up resources used by the Buttons class. Since no dynamic memory 
 * allocation is performed, no specific cleanup operations are required.
 */
Buttons::~Buttons() {

    // No dynamic memory allocation required
}

/**
 * @brief  Initializes the Buttons instance for operation.
 * 
 * This method configures the debounce and hold times for the button matrix.
 * It prepares the `keys_` object to handle button presses with minimal delay.
 * 
 * @details
 * - `setDebounceTime`: Sets the debounce time to 1 ms to filter out spurious presses.
 * - `setHoldTime`: Sets the hold time to 1 ms to detect long presses quickly.
 */
void Buttons::begin() {

    keys_.setDebounceTime(1);
    keys_.setHoldTime(1);
}

/**
 * @brief  Polls and processes key press events for the button matrix.
 * 
 * This method continuously checks the state of keys, processes events such as 
 * presses and releases, and updates the corresponding data. Debug information 
 * is logged if debug mode is enabled.
 * 
 * @details
 * - `getKey`: Retrieves the currently pressed key, if any.
 * - `keyStateChanged`: Checks if the state of any key has changed.
 * - `getState`: Determines the current state of the key (e.g., PRESSED or RELEASED).
 * - Debug output includes the key events and their data before and after updates.
 * 
 * @note Debug mode (`LUSMDL_DEBUGMODE`) must be enabled to see the debug logs.
 */
void Buttons::listener() {

    // Poll and process key presses
    
    char eventKey = keys_.getKey(); // Necessary to get the data for the other methods
    
    if (eventKey) {

        #ifdef LUSMDL_DEBUGMODE
        Serial.print("Key Pressed Event at key " + String(eventKey) + "\n");
        #endif
        lasteventkey_ = eventKey;
    }

    #ifdef LUSMDL_DEBUGMODE
    if (keys_.keyStateChanged()) {

        Serial.print("Key state change at key " + String(lasteventkey_) + "\n");
    }
    #endif


    switch (keys_.getState()) { // Only one key can be pressed at each cycle!!

        case PRESSED:

            // Handle pressed event
            
            #ifdef LUSMDL_DEBUGMODE
            Serial.print("key state PRESSED at key " + String(lasteventkey_) + " old value was " + String(data_[getmap(lasteventkey_)].pushed));
            #endif

            data_[getmap(lasteventkey_)].pushed++; 
            
            #ifdef LUSMDL_DEBUGMODE
            Serial.print(" and the new value is " + String(data_[getmap(lasteventkey_)].pushed) + "\n");
            #endif

            break;
            
        case RELEASED:

            // Handle released event

            #ifdef LUSMDL_DEBUGMODE
            Serial.print("key state RELEASED at key " + String(lasteventkey_) + " old value was " + String(data_[getmap(lasteventkey_)].pushed));
            #endif

            data_[getmap(lasteventkey_)].pushed = 0; 

            #ifdef LUSMDL_DEBUGMODE
            Serial.print(" and the new value is " + String(data_[getmap(lasteventkey_)].pushed) + "\n");
            #endif

            break;
    }
}

/**
 * @brief  Retrieves the data associated with a specific button.
 * 
 * This method returns the `pod_button` data for the button identified by the 
 * specified index in the button matrix.
 * 
 * @param  button The index of the button in the matrix (0-based).
 * @return The `pod_button` data structure containing the button's state and related information.
 */
pod_button Buttons::getData(uint8_t button) {

    return data_[button];
}

/**
 * @brief  Maps a character key to its corresponding index in the button matrix.
 * 
 * This method converts a key character (e.g., 'A', 'B', etc.) to a 0-based index 
 * used in the button matrix. If the key is not defined, it returns `255` to 
 * indicate an invalid key.
 * 
 * @param  key The character key to be mapped (e.g., 'A', 'B', ..., 'P').
 * @return The corresponding index (0-15) for valid keys, or `255` for invalid keys.
 */
int Buttons::getmap(char key) {

    switch (key) {
        case 'A': return 0;
        case 'B': return 1;
        case 'C': return 2;
        case 'D': return 3;
        case 'E': return 4;
        case 'F': return 5;
        case 'G': return 6;
        case 'H': return 7;
        case 'I': return 8;
        case 'J': return 9;
        case 'K': return 10;
        case 'L': return 11;
        case 'M': return 12;
        case 'N': return 13;
        case 'O': return 14;
        case 'P': return 15;
        default: return 255; // Return an invalid value for undefined keys
    }
}
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

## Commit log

2024-07-15 add button.h
2024-07-16 add the circuit and pcb
    [UNO-TH_Rev3e.brd, UNO-TH_Rev3e.kicad_pcb, UNO-TH_Rev3e.kicad_sch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]
2024-07-18 first test runs good in arduino uno envirement
    [circuit.kicad_pcb, circuit.kicad_sch, partlist.csv]
2024-07-19 add some comments and update pcb
    [circuit-B_Cu.gbr, circuit-B_Mask.gbr, circuit-B_Paste.gbr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]
2024-07-19 update circuit
2024-12-21 finish PCBA
    [circuit-B_Cu.gbr, circuit-B_Mask.gbr, circuit-B_Paste.gbr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]
2024-12-22 refactor pcb
    [circuit-B_Cu.gbr, circuit-B_Mask.gbr, circuit-B_Paste.gbr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]
2024-12-23 refactor pcb + generate doxygen file comments (not finished) + new folders + firmwareexport v1.1.0
    [UNO-TH_Rev3e.brd, UNO-TH_Rev3e.kicad_pcb, UNO-TH_Rev3e.kicad_sch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]
2024-12-25 add i2c header
    [circuit-B_Cu.gbr, circuit-B_Mask.gbr, circuit-B_Paste.gbr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]
2024-12-25 update pcba picture
2024-12-26 add joystick connecting over rj45
    [circuit.kicad_pcb, circuit.kicad_sch]
2024-12-27 update pcb and documentation
    [circuit.kicad_pcb, circuit.kicad_sch]
2025-01-14 update Fertigungsdaten
    [circuit-B_Cu.gbr, circuit-B_Mask.gbr, circuit-B_Paste.gbr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]
2025-05-10 update pcb to Rev v1.1.1 (no changes)
    [circuit.kicad_pcb, circuit.kicad_sch]
